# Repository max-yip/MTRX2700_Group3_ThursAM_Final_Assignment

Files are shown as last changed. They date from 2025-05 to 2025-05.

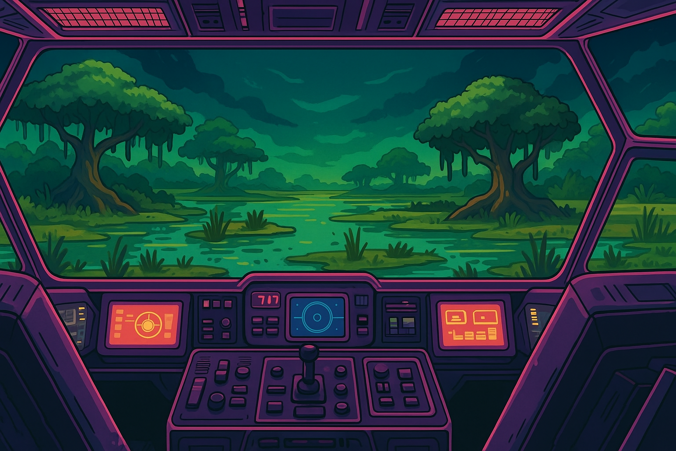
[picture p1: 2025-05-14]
code/GUI_interface/assets/space_bg_swamp.png

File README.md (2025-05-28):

# MTRX2700_Group3_ThursAM_Final_Assignment

## Group Members
Paul Akle 530483944 <br>
Max Yip 520434307 <br>
Siya Sharma 510451145 <br>
Shuvayu Banerjee 540752353 <br>

## Assignment Purpose
To design and implement proof-of-concept technology for a high-tech treasure hunt experience by incorporating a number of different
microcontroller subsystems, sensors, and an actuator.

## Roles and Responsibilities

### Paul Akle
- **Integration:**
  - Challenge 2 & 3 integration
- **Software Interfaces:**
  - Break beam sensor module
  - Servo motor control
  - Flexible potentiometer module
- **Design**
  - Phycial cardboard models (puzzles 2+3)

### Max Yip
- **Integration:**
  - Challenge 1 & 4 integration
- **Software Interfaces:**
  - PyQt GUI design and implementation
  - PTU module
  - Sensor data filtering and serialisation
- **Sensing and Detection:**
  - LDR color detection
- **Design & Documentation:**
  - CAD modeling

### Siya Sharma
- **Display and Sensing Interfaces:**
  - LCD display module
  - LDR sensor module
- **Game Design:**
  - Game mechanics and challenge development

### Shuvayu Banerjee
- **Mechanical Design:**
  - CAD modeling
  - Materials sourcing and procurement
- **Software Interfaces:**
  - Servo motor

## Repository Overview
### File Structure
```
CAD/                                   # All the CAD files (including STEP AND STL can be found here
code/
  ├── modules and interfaces/          # Individual modules that are not required for the challenges
  └── major_project_ptu/               # STM Project for Challenge 1
  └── GUI_interface/                   # PyQt6 GUI for Challenge 1
  └── puzzle_major_project/            # STM Project for Challenge 2 & 3
  └── major_project_lightsaber/        # STM Project for Challenge 4
minutes/                               # Meeting minutes
```

## Project Overview
<details>
  <summary>Challenge 1</summary>
  
  ### Triangulating the hidden planet location

  The player is tasked to locate the hidden planet by measuring the distances of the nearest 3 stars before the fuel runs out.
  
  ### How it works
  1. Users will be required to control the servos of the PTU through the GUI to adjust the lidar to point towards the correct planet.
  2. As the user moves the PTU, the GUI will display the distance and indicate whether the angle of the PTU is correct. The user will have to get the coordinates before moving onto the next planet.
  3. Once the player gets the distance or the timer runs out, the STM32 will signal the GUI to move onto the next planet.
  4. Once all the distances are obtained, it will reveal coordinates to the hidden planet.
  5. Move on to the next challenge: during the travel, the user encounters an asteroid field and is required to shoot them down.

  ### Code Structure Diagram
  puzzle2_2 drawio

  ### Additional Features
  - **Pop-up windows**  
    - At the beginning, to give the user the background of the game  
    - User feedback on whether the distances measured from the PTU are correct  
    - Final pop-up window directing the user to the next challenge  

  - **Chatbot**  
    - Friendly cat companion that gives hints to guide the user throughout the entire treasure hunt
  
</details>

<details>
  <summary>Challenge 2</summary>
  
  ### Asteroid Attack
  After locating the planet the player experiences an astroid field right before entering the planets atmosphere where 8 astroids must be sucessfully hit to make it to the planets surface.

  ### How it works
  1. The user will aim a laser beam and flick towards the astroid
  2. The IR beam breaker sensor will be placed on either side of the lasers path and will detect the object passing through
  3. Each time this occure one of the eight LEDs on the STM discovery board will light up untill all 8 astroids are destroyed

  ### Flowchart
  puzzle2_2 drawio

</details>
<details>
  <summary>Challenge 3</summary>
  
  ### Map Coordinates with Flexible Potentiometer
  After the user makes it to the surface of the planet they must now determine the correct coordinates of the crystal 

  ### How it works
  1. On a locating device there are two flexible potentiometers, one represents the x-ccordinate and the other represents the y-coordinates
  2. By applying pressure on different spots along the potentiometer will generate different values
  3. The interface will tell the user if they are closer or further from the true coordinates compared with their previous attempt
  4. After landing on the correct coordinates the display will tell the user to go to those coordinates on the grid
  5. A servo is intigrated with the determination of the correct coordinates, which when achieved will rotate 90 degrees to open the lid of the correct grid space
  6. An LDR inside this gridspace will detect the light and display a message on a LCD to retreive the crytal and place it in the hilt of the lightsaber

  ### Sersors + Actuators used
  1. 2x Flexible potentiometers
  2. Directional servo motor
  3. Light detecting resistor (LDR)
  4. Liquid-crystal Display (LCD)

  ### Flowchart
  puzzle3 drawio

</details>

<details>
  <summary>Challenge 4</summary>

  ### Assembling the Lightsaber
  The final step in this treasure hunt is to verify that the crystal obtained from challenge 3 is the correct one.

  ### How it works
  1. User will insert the crystal into the hole inside the lightsaber hilt.
  2. The colour detection system will determine the colour of the crystal.
  3. When the user presses a button, the LED will either glow green (if a green crystal is inserted), red (if a red crystal is inserted), or remain off if no colour is detected.

</details>

## Modules
<details>
<summary>GUI interface</summary>

### Summary
This module serves as the **GUI control panel** for user interaction with the **Pan-Tilt Unit (PTU)** in Challenge 1. It provides both **control** and **feedback** for PTU servo positions via UART communication, and handles **game logic** such as planet progression, fuel consumption, and hints.

### File Structure
```
main.py                 # Entry point to launch GUI
ui/
  ├── main_window.py    # Top-level window layout
  ├── center_panel.py   # Central panel with coordinate logic
  ├── left_panel.py     # Planet info and sliders
  └── right_panel.py    # Chatbot and status indicators
core/
  ├── logic.py          # Game logic handling (planet state, validation)
  └── serial_handler.py # Serial communication with STM32
assets/
  └── images/           # UI image resources
```

### Usage
1. **Connect** STM32 board with PTU attached via USB.
2. Ensure PyQT6 installed, build version is using python3.12.1
2. In `main_window.py` (around line 31), **ensure the correct COM port** is specified for the STM32 board.
3. Run the GUI:
  ```bash
  python3 main.py
  ```

### Functionalities

- **Sliders**:  
  - Two sliders control **pan** and **tilt** angles of the servos.
  
- **Next Planet Button**:  
  - Advances to the next planet once current target is complete.

- **Calculate Coordinate Button**:  
  - Validates all 3 distances and PTU orientation for accuracy.

- **Fuel Bar**:  
  - Decreases if the player inputs incorrect distance/orientation.

- **Chatbot**:  
  - Offers hints during the treasure hunt when prompted by user.

### Valid Input

- Ensure **serial format** in `serial_handler.py` matches the STM32 firmware.
- Correct **COM port** is configured in the GUI.
- Servo positions (pan/tilt) must match pre-defined **target coordinates** (to be added).

### Functions and Modularity

- `main.py`  
  - Initializes and launches the main GUI window.

- `serial_handler.py`  
  - Handles UART communication with STM32.

- `logic.py`  
  - Contains game logic, position validation, planet progression.

- `main_window.py`  
  - Assembles all UI panels and manages layout.

- `left_panel.py`  
  - Contains sliders and planet visuals.

- `center_panel.py`  
  - Displays coordinates, fuel bar, and validation controls.

- `right_panel.py`  
  - Manages chatbot interaction and game messages.

### Testing

- **Slider Limitations**:  
  - Cannot set slider values by clicking—must be **manually dragged** to send values to STM32 correctly.

- **Chatbot Testing**:  
  - Ask for hints multiple times to confirm chatbot randomness and reliability.

- **Functional Testing**:  
  - Interact with all controls:
    - Adjust pan/tilt sliders
    - Validate coordinates
    - Use next planet button
    - Trigger fuel bar reduction
    - Request hints via chatbot
    - Ensure serial communication and game logic run smoothly

</details>

<details>
  <summary>PTU</summary>

### Summary
This module enables interfacing with the Pan-Tilt Unit through UART. It controls:
- 2 servos (pan, tilt)
- 1 LIDAR-Lite v3 distance sensor
- 3-axis gyroscope (L3G4200D)
- 3-axis accelerometer (ADXL345)
- 3-axis magnetometer (HMC5883L)

This is the main interface for Challenge 1 where users must orient servos to take accurate distance measurements.

---

### Sub-modules

#### Servo Drivers
**File**: `ptu_servo.h`

##### Usage
- `HAL_StatusTypeDef initialise_ptu_pwm(TIM_HandleTypeDef *htim1, TIM_HandleTypeDef *htim2)`  
  Initializes timers 1 & 2 for the two servos.

- `void setServoPWM(uint16_t vertical_PWM, uint16_t horizontal_PWM)`  
  Sets pan and tilt servo PWM values.

- `void servo_command_parser(SerialPort *serial_port)`  
  Debugging parser (no serialization) to directly set PWM via serial.

##### Functionalities and Features
- Servo changes are triggered by serial interrupts from the GUI.
- Both servos can be controlled simultaneously, but the GUI allows one at a time.

##### Testing
- Print statements on GUI confirm servo positioning.
- Command parser allows standalone testing (bypassing serialization).
- PWM values are clamped to slider bounds.

---

#### LIDAR
**File**: `ptu_lidar.h`

##### Usage
- `void HAL_TIM_IC_CaptureCallback(TIM_HandleTypeDef *htim)`  
  Timer callback for PWM input (auto-triggered; do not call manually).

- `uint16_t last_period`  
  Stores the most recent measured distance in mm.

##### Functionalities and Features
- Distance is updated via interrupt on each pulse from LIDAR.
- Includes median filtering for noise reduction.
- Max reading capped at 4000 mm (4 meters).

##### Testing
- Test using objects at known distances (e.g. ruler).
- Validate units (mm) and output via GUI.
- Confirm proper serialisation to GUI.

---

#### Gyroscope and Accelerometer
**File**: `ptu_i2c.h`

##### Usage
- `void initialise_ptu_i2c(I2C_HandleTypeDef *i2c)`  
  Initializes I2C interface for sensors.

- `void read_gyro_data(I2C_HandleTypeDef *i2c, int16_t *yaw, int16_t *pitch, int16_t *roll)`  
  Reads gyroscope data.

- `void read_accel_data(I2C_HandleTypeDef *i2c, int16_t *acc_x, int16_t *acc_y, int16_t *acc_z)`  
  Reads accelerometer data.

##### Notes
- Currently unused, but intended for future Kalman filtering to estimate tilt.
- Will replace GUI dials with real-world orientation estimates.

##### Testing
- Output raw data via serial for verification.
- Connect to GUI and confirm readable, filtered data.
- Filter test: output should be ~0 if signal frequency < half window size.

---

#### Helper Modules

**`filters.h`**
- `void initFilters(Filter *filters, uint16_t init_value)`  
  Initializes sliding window filters.

- `uint16_t getMedian(Filter* filter, uint16_t new_value)`  
  Computes median-filtered output.

- `uint16_t getMovingAverage(Filter* filter, uint16_t new_value)`  
  Computes moving average output.

**`ptu_definitions.h`**
- Contains all sensor register mappings and I2C constants.

**`serial.h and serialisation.h`**
- Packs all sensor data and sends it to the GUI.
- Uses sentinel bytes and headers for reliable parsing.

</details>

<details>
  <summary>Flex pot sensor</summary>
  
### Flexible Potentiometer (flexpot.c)
### Summary
This module configures ADC1 on PC0 (ADC_IN6) and PC2 (ADC_IN8) to read input from two flexible potentiometers. It provides a simple API to initialize the ADC hardware and perform one-shot conversions on a specified channel, returning a discrete position value (1–6) or 0 to indicate no touch.

### Usage
1. Initialization
Call:
`FlexPot_Init();`

This:
  - Enables clocks for GPIOC and ADC1
  - Configures PC0 and PC2 in analog mode
  - Calibrates and enables ADC1

2. Reading a Position
To read from a specific potentiometer channel:
`uint8_t pos = FlexPot_GetPosition(channel);`
Where:
  - `channel` is `6` for PC0 or `8` for PC2
  - Return value pos is:
    - `0` if no touch (`raw < 100`)
    - `1–6` depending on pressure/location along the strip

### Valid Input

- channel must be:
    - `6` → PC0 → ADC_IN6
    - `8` → PC2 → ADC_IN8

- Internally:
    - Raw ADC values < 100 are considered no touch and return 0
    - Values ≥ 100 are linearly mapped to positions 1–6
      (1 = bottom, 6 = top of the strip)

### Functions and Modularity

- `void FlexPot_Init(void)`
 Initializes GPIOC and ADC1:
    - Enables clocks
    - Sets PC0 and PC2 to analog mode
    - Calibrates and powers on ADC1

- `uint8_t FlexPot_GetPosition(uint8_t channel)`
Reads the flexible potentiometer:
  - Sets the selected ADC channel (6 or 8)
  - Starts and waits for ADC conversion
  - Reads `ADC1->DR`
  - Applies a "no-touch" threshold
  - Maps 12-bit ADC value (0–4095) to discrete values `0–6`

### Testing

- No Touch Test:
Leave the potentiometer untouched → should return 0

- Endpoint Test:
Press firmly at the start or end of the strip → should return 1 or 6

- Integration Test:
In your puzzle game, read X/Y positions using:

`uint8_t x = FlexPot_GetPosition(6);
uint8_t y = FlexPot_GetPosition(8);`

Send both values over UART periodically and confirm the output matches physical input location.

</details>

<details>
  <summary>Break Beam Sensor </summary>
  
### IR Beam Breaker Sensor (beam.c)
  
### Summary
This module configures PC1 as an EXTI1 (falling‐edge) interrupt input to detect when an IR beam is broken. Each beam break increments a counter (`beam_count`, up to 8) and lights the corresponding Discovery-board LED (PE8…PE15). A simple API lets you query or reset the count (and LEDs).
### Usage
1. Initialization
At the start of your program, call `Beam_Init();`
This:
    - Enables GPIOC and GPIOE clocks
    - Configures PC1 as an EXTI1 input with falling-edge interrupt
    - Enables EXTI1 interrupt in NVIC
    - Sets up PE8–PE15 as outputs for LED indication

2. Reading the Count
In your application code, use:
`uint8_t n = Beam_GetCount();`
This returns the number of beam breaks detected so far (max 8).

2. Resetting the Count and LEDs
To reset the counter and turn off LEDs:
`Beam_ResetCount();`

### Valid Input
- An object must break the IR beam, pulling PC1 low and triggering a falling edge.
- Only transitions from high to low increment `beam_count` (debounced via hardware or design).
- The counter saturates at 8; additional breaks do not increase the count or light further LEDs.
- No input (i.e., beam never broken) is treated as a failure condition in the game.

### Functions and Modularity
- `void Beam_Init(void)`
Initializes GPIOC and GPIOE. Configures PC1 for EXTI1 (falling edge) and sets PE8–PE15 as LED outputs.
- `uint8_t Beam_GetCount(void)`
Returns the current value of beam_count.
- `void Beam_ResetCount(void)`
Resets beam_count to 0 and turns off all LEDs.
- `void HAL_GPIO_EXTI_Callback(uint16_t GPIO_Pin)`
Called automatically by HAL on EXTI interrupts. If the pin is PC1 and it reads low:
  - Increments `beam_count` (if < 8)
  - Lights the corresponding LED (PE8 + count index)

### Testing
To test the boundary conditions the beam breaks more than eight times which should result in no further LEDs lighting up or overflow to occur.
To test integration the main file code with the flex-pot code is tested to ensure the two modules operate without interfering (e.g. ADC vs EXTI).
1. Boundary Test:
Trigger the beam more than 8 times. The count should stop incrementing and no extra LEDs should light.

2. Integration Test:
Run the beam module alongside other sensor modules (e.g., Flex Potentiometer using ADC). Verify:
    - EXTI and ADC operate independently.
    - No conflicts or race conditions between modules.

</details>

<details>
  <summary>LCD display</summary>
  
  ### Summary
  
  This module provides an interface for controlling a 16x2 HD44780-compatible LCD over I2C using STM32 HAL libraries. It uses an I2C I/O expander (e.g., PCF8574) to communicate with the LCD in 4-bit mode. This reduces GPIO usage and simplifies wiring, ideal for STM32CubeMX-based projects.

The module allows for easy initialization, cursor control, string display, and command-level manipulation. 

The LCD is connected to GPIO port D using the following pin mapping:
- GND --> GND
- VDD --> 5V
- SCL --PA6
- SDA --> PA7

The module is designed for portability and ease of integration with STM32CubeMX-based projects.

  ### Usage

#### 1. Include the module
In main.c or any relevant source file:
`#include "i2c.h"`

#### 2. Include the module
Initialize LCD in your main function
```
HD44780_Init(2);                  // 2-line LCD
HD44780_Clear();
HD44780_PrintStr("Place crystal on handle!");
```

  ### Valid Input
1. Rows: 0 or 1
2. Columns: 0 to 15
3. Characters: Standard ASCII text (the LCD does not support Unicode)
4. Strings: Null-terminated (char *), max 16 characters per line (extra characters wrap if not managed)

  ### Functions 

- `void void HD44780_Init(uint8_t rows)`
Initializes the LCD in 4-bit mode.

- `void HD44780_Clear(void)`
Clears the LCD display.

- `void HD44780_Init(uint8_t rows)`
Initializes the LCD in 4-bit mode with the specified number of rows.

- `void HD44780_Clear(void)`
Clears the display.

- `void HD44780_SetCursor(uint8_t col, uint8_t row)`
Sets the cursor to the given column and row.

- `void HD44780_PrintStr(const char str[])`
Prints a null-terminated string.

- `void HD44780_Cursor(void)`
Shows the cursor.

- `void HD44780_NoCursor(void)`
Hides the cursor.

- `void HD44780_Blink(void)`
Enables blinking cursor.

- `void HD44780_NoBlink(void)`
Disables blinking cursor.

- `void HD44780_Backlight(void)`
Turns on the backlight.

- `void HD44780_NoBacklight(void)`
Turns off the backlight.

- `void HD44780_CreateSpecialChar(uint8_t index, uint8_t data[])`
Loads a custom character (up to 8).

- `void HD44780_PrintSpecialChar(uint8_t index)`
Prints a previously created special character.

- `void HD44780_ScrollDisplayLeft(void) / HD44780_ScrollDisplayRight(void)`
Scrolls display left/right.

  ### Modularity
All functions are encapsulated in `i2c.c` and `i2c.h`. The module relies solely on HAL I2C and minimal MCU core resources (DWT for delay). It can be easily reused across STM32 projects with similar hardware configuration.

  ### Testing 
1. Confirm LCD initializes and displays static text using `HD44780_PrintStr()`.
2. Test cursor positioning with `HD44780_SetCursor(row, col)`.
3. Test scrolling and blinking using display control functions.
4. Load and print custom characters with `HD44780_CreateSpecialChar()` and `HD44780_PrintSpecialChar()`.

#### Debug Tips
1. Ensure correct I2C address (0x27 << 1 for PCF8574).
2. Check LCD contrast by adjusting the potentiometer on V0.
3. If LCD remains blank:
     - Verify I2C connection (SCL, SDA continuity).Confirm LCD receives enable pulse (use oscilloscope).
     - Check backlight and 5V power supply.

</details>
<details>
  <summary>LDR</summary>

### Summary
This module uses an LDR (Light Dependent Resistor) for two purposes:
1. **Light Detection**  
   - Measures ambient brightness.
   - Compares against a preset threshold to trigger logic changes.

2. **Colour Detection**  
   - Detects the amount of reflected light when red, green, and blue LEDs are sequentially illuminated.
   - Determines the dominant reflected wavelength to identify the surface colour.

---

### Sub-modules

#### Colour Detection State Machine  
**File**: `colour_detector.h`

##### Description
A state machine implemented via `switch-case` inside a timer callback:
- **States**:  
  `INIT → RED_ON → READ_RED → GREEN_ON → READ_GREEN → BLUE_ON → READ_BLUE → DETECT_COLOUR`

- **Calibration**:  
  On first run (`calibrate = 0`), records initial ambient brightness to normalize readings.

- **Debugging**:  
  When colour is detected, an optional final state transmits a string over serial for monitoring.

##### Usage
- Timer interrupt calls the `handleStateMachine()` function at a fixed interval.
- LED GPIOs are toggled within each state to control colour sequencing.

---

#### ADC Functions  
**File**: `adc.c`

##### Core Functions
- `void initialiseSingleADC()`  
  Manually configures ADC1 to single-shot mode.

- `uint16_t singleReadADC()`  
  Performs a one-time read of the ADC value, used in the colour detection state machine.

##### Optional Utilities
- `void continuousReadSingleChannelADC()`  
  Continuously polls a single ADC channel in a blocking loop using the `ISR` register.

- `void SingleReadMultiChannelADC()`  
  Reads multiple channels on the same ADC (currently unused in this module but available for expansion).

---

### Functionalities and Features
- Ambient light detection with threshold-triggered variable setting.
- RGB LED-controlled surface reflection sensing to classify colours.
- Compact state machine for cyclic LED control and ADC reading.
- Lightweight implementation using timer-driven ADC sampling.

---

### Usage

```c
int main(void) {
    enableGPIODLEDS();
    enableGPIOClocks();

    serialInitialise(BAUD_115200, &USART1_PORT, 0x00);

    initialiseSingleADC();

    // Start colour detection state machine on timer callback
    setTIM2Callback(&handleStateMachine);
    init_TIM2(50); // Timer interval set to 50ms
}
```

---

### Testing
- Use serial output to confirm detection states and transitions.
- Calibrate under various lighting conditions to test ambient compensation.
- Use known-colour surfaces and compare detection accuracy.
- Evaluate ADC signal stability under continuous and single-shot reads.

</details>

<details>
  <summary>Servo Motor</summary>

  ### Summary
This module allows control of a servo motor via PWM (TIM2 CH1) on the STM32F3DISCOVERY board. Pressing the blue user button (PA0) triggers an rising-edge EXTI0 interrupt that calls a callback function, rotating the servo to a fixed angle (90°). The PWM signal is continuously generated on PA15 (TIM2_CH1). All hardware logic is modularised into a clean `servo.c` and `servo.h` interface.

  ### Usage
This section explains how to use the digital button (PA0) for controlling the servo motor. All functionality is interrupt-based, so no button polling or delay loops are needed.

---

#### 1.Include the Header:
At the top of your `main.c` file, include the servo module:
```c
#include "servo.h"
```
2. Setup in main():
Call these functions once in `main()` to initialize everything:

```c
enable_clocks();                      
enableGPIOAButton();                   

on_button_press = &rotate_servo_90;         

enable_interrupt();                   
```
3. Main Loop:
loop forever and there is nothing happening in the main while loop since everything is interrupt driven:
```c
while (1)
  {
    /* USER CODE END WHILE */

    /* USER CODE BEGIN 3 */
  }
```
4. What Happens:
* When the system powers on, all required peripherals (GPIOs, I2C, SPI, USB, and TIM2) are initialized.
* Timer 2 is started to generate a continuous PWM signal used to control a servo motor.
* The blue user button (PA0) is configured to trigger an interrupt when pressed.
* A call-back function is assigned to run automatically whenever the button is pressed.
* Once the interrupt is enabled, the program enters an infinite loop — but nothing happens here because the logic is interrupt-driven.
* When the user presses the button, the rising edge triggers an interrupt in the background.
* This causes the assigned servo-control function to run, which updates the PWM signal’s duty cycle.
* The updated PWM pulse tells the servo to rotate to a new position (90°).
* No repeated button presses will move the servo again unless the PWM value is updated again.
  
  ### Valid Input
The module expects the following valid inputs and formats:

* Button Press	- The user presses the on-board button (PA0), triggering the EXTI0 interrupt.

  ### Functions and Modularity
The code is separated into a header (servo.h) and implementation (servo.c) to support clean modularity and easy reuse.

**Functions:**

#### `enable_clocks()`
**Purpose:**  
Turns on the clocks (power) to the GPIO ports A, C, and E.

**When to call it:**  
At the beginning of your `main()` function — before setting up pins or using any peripherals.

---

### `void enableGPIOAButton(void)`
**Purpose**:  
Configures PA0 (the user button) as a digital input.

**How it Works**:  
Clears the mode bits in `GPIOA->MODER` for pin 0, putting it in input mode.

**When to Call**:  
Call once during setup, after clocks are enabled and before enabling interrupts.

---

### `void enable_interrupt(void)`
**Purpose**:  
Sets up external interrupts on PA0 to detect button presses.

**How it Works**:
- Enables the SYSCFG peripheral.
- Maps PA0 to EXTI0 (external interrupt line 0).
- Configures EXTI0 to trigger on a rising edge (i.e., button press).
- Enables EXTI0 in the NVIC (Nested Vectored Interrupt Controller).
- Globally enables interrupts using `__enable_irq()`.

**When to Call**:  
Call after assigning `on_button_press` and after enabling clocks and GPIOA input. Only needs to be called once.

---

### `void (*on_button_press)()`
**Purpose**:  
A function pointer that stores the action to take when the button is pressed (e.g., rotate the servo).

**How it Works**:  
You assign this in `main()` like so:  
```c
on_button_press = &rotate_servo_90;
```

#### `EXTI0_IRQHandler(void)`
**Purpose:**  
This is the interrupt service routine (ISR) for button press.

**What it does:**  
* When PA0 is pressed, this runs automatically
* It checks if on_button_press is set (not NULL)
* If set → it runs that function (toggleLED())
* Clears the EXTI0 interrupt flag

**When it runs:**  
Every time the user presses the button (rising edge on PA0).

---

### `rotate_servo_90(void)`

**Purpose**  
Moves the servo motor to the 90-degree position using PWM signals.

**How it Works**  
This function sets the compare values of TIM2’s channels (CCR1 and CCR2) to `1800`, which corresponds to a pulse width of approximately **1.5ms**. That’s the standard signal to tell most hobby servos to move to the **center or 90°** position.  

The PWM timer (already running in the background) uses these values to continuously send the correct high pulse width to the servo.

- `TIM2->CCR1 = 1800;`  
- `TIM2->CCR2 = 1800;`  

This assumes that the timer is configured for a **20ms period (50Hz)**, so:
- ~1ms pulse → 0°
- ~1.5ms pulse → 90°
- ~2ms pulse → 180°

**When to Call It**  
- You assign this function to the `on_button_press` pointer in `main()`.
- When the button is pressed, the EXTI0 interrupt fires and automatically calls this function.

  ### Testing 
This section shows how to test the servo code reliably, not just by observation but also using in-code checks.

---

#### Button Press Test

**Goal:** Check that pressing the blue user button rotates the servo.

**Steps:**
1. Connect servo:
   - Signal: PA15
   - VCC: 5V
   - GND: GND
2. Flash the code and run the board.
3. Press the user button.

**Expected:** Servo rotates to the 90° position.

---

#### Debug with LED Toggle

**Goal:** Confirm code execution using an LED.

**How:**
Add this to `rotate_servo_90()`:
```c
GPIOE->ODR ^= GPIO_ODR_9; // Toggle LED on each press
```

</details>

Code from **MTRX2700-2025** was used and refactored, and code from **ThursAM_Group6_CLab** was used in this assignment.

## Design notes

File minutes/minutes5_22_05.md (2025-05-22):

## Meeting Details 
# MTRX Group #3 
**Date:** 22/05/2025  
**Time:** 9:00 AM
**Location:** Tutorial session  
**Meeting Type:** Design and interface finalisation, discussing working parts   

## Attendance  
| Name | Status | Notes |
|---|---|---|
| Max Yip | Present  |  |
| Aditya Kathane | Present | Left early |
| Siya Sharma | Present  |  |
| Paul Akle | Present  |  |
| Shuvayu Benerjee | Present  |  |

## Agenda  
- [x] **Item 1** - Implement game logic
- [x] **Item 2** - Finalise current sensor interfaces
- [x] **Item 3** - Integrate interfaces to perform puzzles

## Action Items  
| Task | Assigned To | Due Date | Status |
|---|---|---|---|
| Build physical game interface + Integration| Paul Akle | Week 12 | In Progress |
| Try to get ldr colour detection working and finish up puzzle 1 game logic | Max Yip | Week 12 | In Progress |
| Servo Interface | Aditya Kathane | Week 9 | Unknown |
| LDR + LCD screen interface | Siya Sharma | Week 12 | Completed |
| 3D print required objects | all | Week 12 | Completed  |
| Readme for servo | Shuvayu Benerjee | Week 12 | In Progress  |

## Next Steps  
- **Next Meeting:** In-person meeting next Monday (27/5/25)  
- **Objectives for Next Meeting:**  
  - [ ] Objective 1: Complete all sensor interfaces 
  - [ ] Objective 2: Implement integration of modules
  - [ ] Objective 3: Finsh Game logic code for puzzles
  - [ ] Objective 4: Write up ReadMe

---
*End of Meeting Minutes*

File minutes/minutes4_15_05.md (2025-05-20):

## Meeting Details 
# MTRX Group #3 
**Date:** 15/05/2025  
**Time:** 10:00 AM
**Location:** Tutorial session  
**Meeting Type:** Design and interface finalisation, discussing working parts   

## Attendance  
| Name | Status | Notes |
|---|---|---|
| Max Yip | Present  |  |
| Aditya Kathane | Absent  |  |
| Siya Sharma | Present  |  |
| Paul Akle | Present  |  |
| Shuvayu Benerjee | Present  |  |

## Agenda  
- [x] **Item 1** - Implement game logic
- [x] **Item 2** - Finalise current sensor interfaces
- [x] **Item 3** - Integrate interfaces to perform puzzles

## Action Items  
| Task | Assigned To | Due Date | Status |
|---|---|---|---|
| Build physical game interface + Integration| Paul Akle | Week 12 | In Progress |
| Try to get ldr colour detection working and finish up puzzle 1 game logic | Max Yip | Week 12 | In Progress |
| Servo Interface | Aditya Kathane | Week 9 | Unknown |
| LDR + LCD screen interface | Siya Sharma | Week 12 | In pogress |
| 3D print required objects | all | Week 12 | Completed  |
| servo code and readme section of the servo | Shuvayu Benerjee | Week 12 | In Progress  |

## Next Steps  
- **Next Meeting:** In-person meeting next Monday (19/5/25)  
- **Objectives for Next Meeting:**  
  - [ ] Objective 1: Complete all sensor interfaces 
  - [ ] Objective 2: Implement integration of modules
  - [ ] Objective 3: Finsh Game logic code for puzzles

---
*End of Meeting Minutes*

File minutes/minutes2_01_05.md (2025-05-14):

## Meeting Details 
# MTRX Group #3 
**Date:** 01/05/2025  
**Time:** 10:00 AM
**Location:** Tutorial session  
**Meeting Type:** Design and interface finalisation   

## Attendance  
| Name | Status | Notes |
|---|---|---|
| Max Yip | Present  |  |
| Aditya Kathane | Absent  | Sick  |
| Siya Sharma | Absent  | Personal reasons |
| Paul Akle | Present  |  |
| Shuvayu Benerjee | Present  |  |

## Agenda  
- [x] **Item 1** - Create a final task description 
- [x] **Item 2** - Finalise current sensor interfaces
- [x] **Item 3** - Create interface for servo and LDR
- [ ] **Item 4** - Begin designing physical interfaces (Planets and Grid)

## Action Items  
| Task | Assigned To | Due Date | Status |
|---|---|---|---|
| Filter code + puzzle 2 design | Paul Akle | Week 10 | In Progress |
| Filter code + lidar and refractor code | Max Yip | Week 10 | In Progress |
| Servo Interface | Aditya Kathane | Week 10 | Unknown |
| LDR interface | Siya Sharma | Week 10 | Unknown |
| Purchase extra flexible potentiometer | all | Week 10 | In Progress  |
| Design planet for puzzle 1 | Shuvayu Benerjee | Week 10 | In Progress  |

## Next Steps  
- **Next Meeting:** In-person meeting next Wednesay (7/5/25)  
- **Objectives for Next Meeting:**  
  - [ ] Objective 1: Complete all tasks before next Thursday 
  - [ ] Objective 2: Have plan for integration ready to begin and implement

---
*End of Meeting Minutes*

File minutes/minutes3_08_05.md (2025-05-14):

## Meeting Details 
# MTRX Group #3 
**Date:** 08/05/2025  
**Time:** 9:00 AM
**Location:** Tutorial session  
**Meeting Type:** Design and interface finalisation, discussing working parts   

## Attendance  
| Name | Status | Notes |
|---|---|---|
| Max Yip | Present  |  |
| Aditya Kathane | Absent  | Preparing for other exam  |
| Siya Sharma | Present  |  |
| Paul Akle | Present  |  |
| Shuvayu Benerjee | Present  |  |

## Agenda  
- [x] **Item 1** - Write up a detailed summary of all parts of the major project and start on progress report due next week 
- [x] **Item 2** - Finalise current sensor interfaces
- [x] **Item 3** - Create interface for servo and LDR
- [ ] **Item 4** - Begin designing physical interfaces (Planets and Grid)

## Action Items  
| Task | Assigned To | Due Date | Status |
|---|---|---|---|
| Filter code + puzzle 2 design | Paul Akle | Week 11 | In Progress |
| Filter code + lidar and refractor code | Max Yip | Week 11 | In Progress |
| Servo Interface | Aditya Kathane | Week 11 | Unknown |
| LDR + LCD screen interface | Siya Sharma | Week 11 | In pogress |
| 3D print required objects | all | Week 11 | In Progress  |
| Design planet for puzzle 1 + servo interface | Shuvayu Benerjee | Week 11 | In Progress  |

## Next Steps  
- **Next Meeting:** In-person meeting next Monday (12/5/25)  
- **Objectives for Next Meeting:**  
  - [ ] Objective 1: Complete filter signal code 
  - [ ] Objective 2: Have plan for integration ready to begin and implement
  - [ ] Objective 3: Start Game logic for puzzle 1

---
*End of Meeting Minutes*

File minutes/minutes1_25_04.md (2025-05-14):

## Meeting Details 
# MTRX Group #3 
**Date:** 25/04/2025  
**Time:** 10:00 AM 
**Location:** Zoom Meeting  
**Meeting Type:** Task conceptialisation and brainstorm 

## Attendance  
| Name | Status | Notes |
|---|---|---|
| Max Yip | Present  |  |
| Aditya Kathane | Absent  |  |
| Siya Sharma | Present  |  |
| Paul Akle | Present  |  |

## Agenda  
- [x] **Item 1** - Demonstrate current ideas and challenges
- [x] **Item 2** - Brainstorm new ideas
- [x] **Item 3** - Create a final task description 
- [ ] **Item 4** - Design of system diagrams 

## Action Items  
| Task | Assigned To | Due Date | Status |
|---|---|---|---|
| IR beam Breaker Interface | Paul Akle | Week 9 | In Progress |
| Create project code base | Max Yip | Week 9 | In Progress |
| Servo Interface | Aditya Kathane | Week 9 | Unknown |
| Stages design | Siya Sharma | Week 9 | In Progress  |

## Next Steps  
- **Next Meeting:** Remote call before next Thursday (Date TBC)  
- **Objectives for Next Meeting:**  
  - [ ] Objective 1: Complete all tasks before next Thursday 
  - [ ] Objective 2: Have plan for integration ready to begin and implement

---
*End of Meeting Minutes*

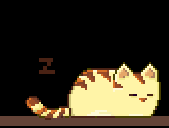
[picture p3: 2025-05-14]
code/GUI_interface/assets/cat_cropped.gif

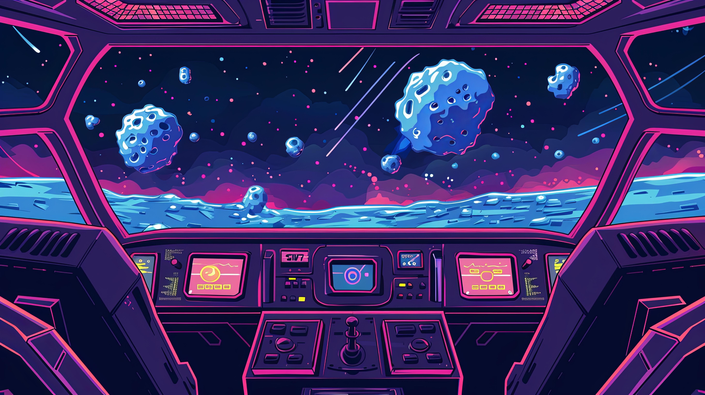
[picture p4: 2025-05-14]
code/GUI_interface/assets/space_bg2.jpg

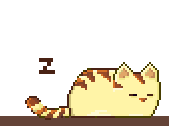
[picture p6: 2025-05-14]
code/GUI_interface/assets/cat_nobg.gif

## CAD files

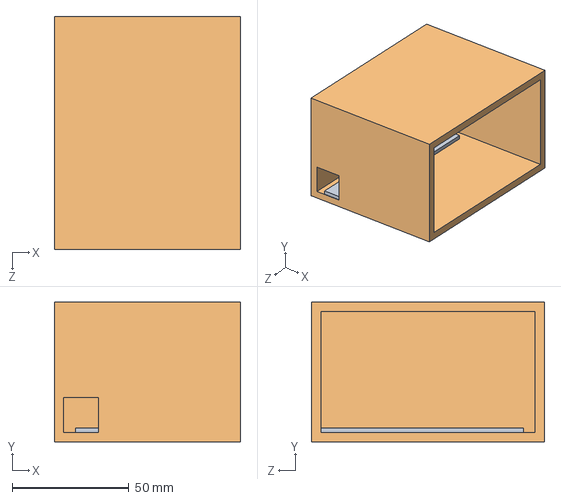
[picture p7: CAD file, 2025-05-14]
CAD/sensor_box.SLDASM
80.0 x 60.0 x 100.0 mm
Pressure Sensor Box
Flex pot placeholder

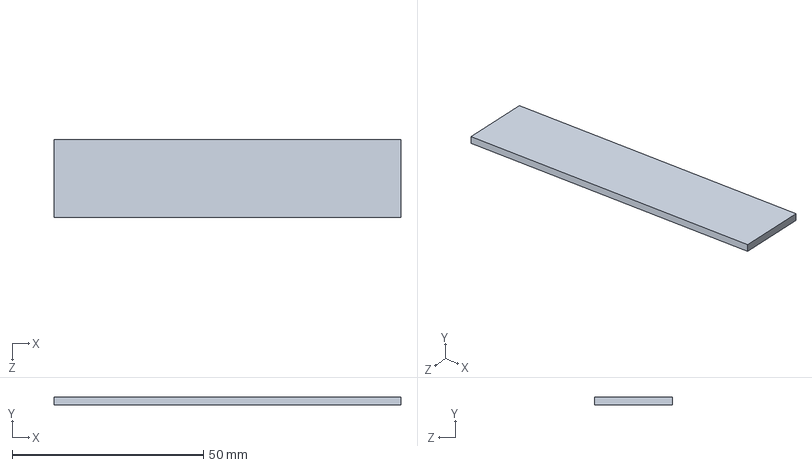
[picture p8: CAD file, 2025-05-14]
CAD/Flex pot placeholder.SLDPRT
90.8 x 2.00 x 20.3 mm

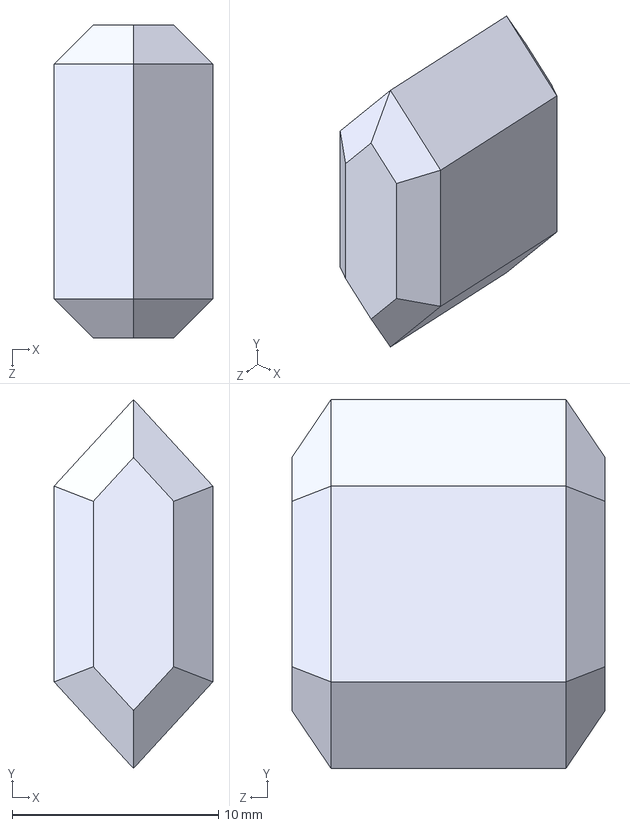
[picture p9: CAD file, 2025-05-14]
CAD/crystal.STEP
7.70 x 17.9 x 15.2 mm

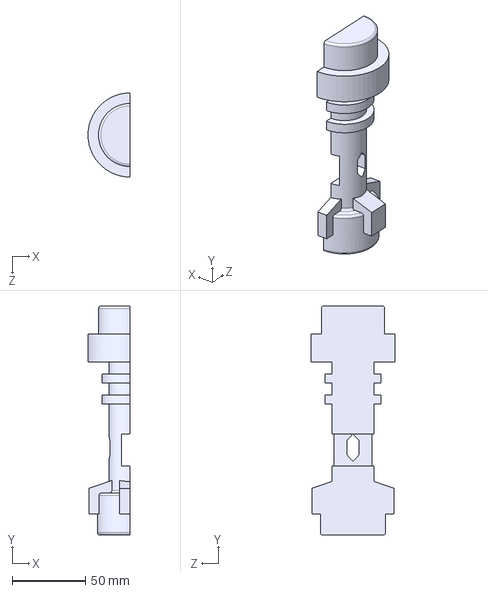
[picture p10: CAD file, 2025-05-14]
CAD/hilt2.STEP
28.8 x 156.8 x 57.6 mm

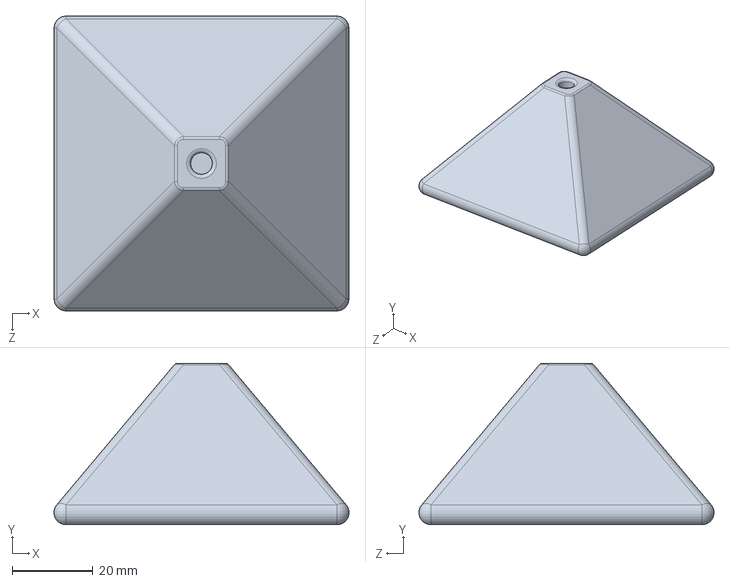
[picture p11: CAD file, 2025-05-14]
CAD/BASE_MTRX2700.SLDPRT
73.1 x 40.0 x 73.1 mm

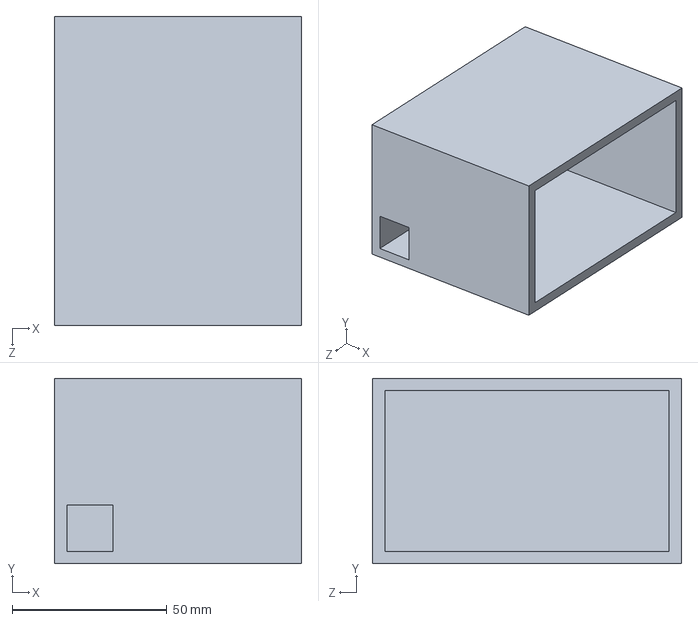
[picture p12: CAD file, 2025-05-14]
CAD/Pressure Sensor Box.SLDPRT
80.0 x 60.0 x 100.0 mm

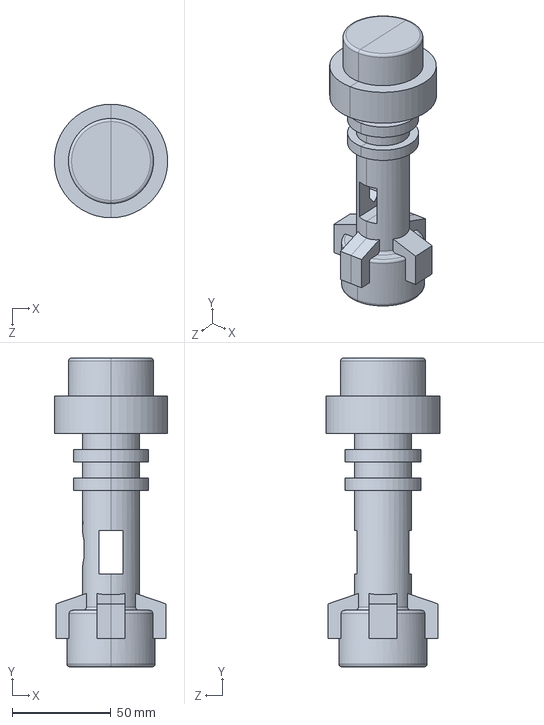
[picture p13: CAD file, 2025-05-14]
CAD/lightsaber hilt.SLDPRT
57.5 x 156.8 x 57.6 mm

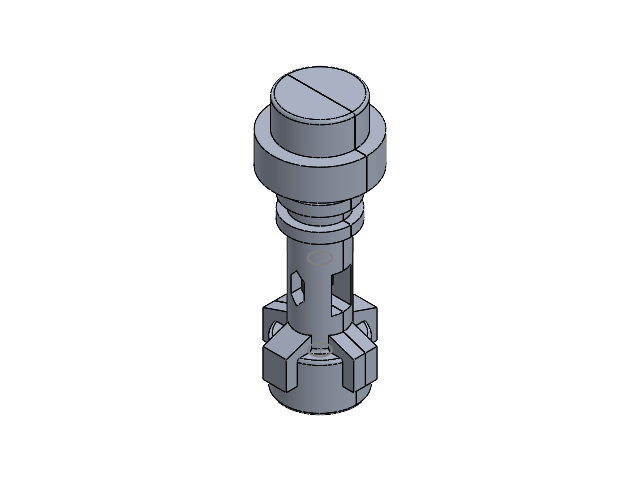
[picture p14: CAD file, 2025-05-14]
CAD/crystal inside lightsaber.SLDASM
crystal
lightsaber hilt

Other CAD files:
CAD/hilt1.STEP
CAD/BASE_MTRX2700.STL
CAD/base_option2.SLDPRT
CAD/base_option2.STL
CAD/crystal.SLDPRT
CAD/crystal.STL
CAD/hilt1.SLDPRT
CAD/hilt1.STL
CAD/hilt2.SLDPRT
CAD/hilt2.STL

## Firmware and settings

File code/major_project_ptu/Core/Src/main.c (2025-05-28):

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
/* Includes ------------------------------------------------------------------*/
#include "main.h"

/* USER CODE BEGIN Includes */
#include "ptu_definitions.h"
#include "ptu_i2c.h"
#include "ptu_servo.h"
#include "ptu_lidar.h"
#include "serial.h"
#include "serialise.h"
#include "gpio.h"
#include "filters.h"
#include <math.h>
/* USER CODE END Includes */

I2C_HandleTypeDef hi2c1;

SPI_HandleTypeDef hspi1;

PCD_HandleTypeDef hpcd_USB_FS;

// timer definition for lidar pwm
TIM_HandleTypeDef htim1;
TIM_HandleTypeDef htim2;


void SystemClock_Config(void);
static void MX_GPIO_Init(void);
static void MX_I2C1_Init(void);
static void MX_SPI1_Init(void);
static void MX_USB_PCD_Init(void);
static void MX_TIM2_Init(void);
static void MX_TIM1_Init(void);
/**
  * @brief  The application entry point.
  * @retval int
  */
int main(void)
{

  /* USER CODE BEGIN 1 */
//	Pin connections
//	SCL to PB6
//	SDA to PB7
//	PWM1 to PA1
//	PWM2 to PA15
//	LASPWM to PA8
//	rest to ground

  /* USER CODE END 1 */

  /* MCU Configuration--------------------------------------------------------*/

  /* Reset of all peripherals, Initializes the Flash interface and the Systick. */
  HAL_Init();

  /* Configure the system clock */
  SystemClock_Config();

  /* Initialize all configured peripherals */
  MX_GPIO_Init();
  MX_I2C1_Init();
  MX_SPI1_Init();
  MX_USB_PCD_Init();
  MX_TIM2_Init();
  MX_TIM1_Init();
  /* USER CODE BEGIN 2 */


	  // Initialise UART serial communication at 115200 baud
	  // and set the command parser callback for servo control
	  serialInitialise(BAUD_115200, &USART1_PORT, &servo_command_parser);

	  // Enable receive interrupt for non-blocking serial input
	  serialReceiveInterrupt(&USART1_PORT);

	  // Initialise I2C interface for the pan-tilt unit (gyro, accel, etc.)
	  initialise_ptu_i2c(&hi2c1);

	  uint8_t return_value = 0x00;

	  return_value = HAL_I2C_Mem_Write(&hi2c1, LIDAR_WR, 0x00, 1, &return_value, 1, 10);
	  if (return_value != HAL_OK) {
	      // Handle I2C error
	      Error_Handler();
	  }

	  return_value = initialise_ptu_pwm(&htim1, &htim2);
	  if (return_value != HAL_OK) {
	      // Handle PWM init failure
	      Error_Handler();
	  }

	  // Create and initialise an array of median filters for sensor data
	  Filter dataFilters[NUM_DATA];
	  initFilters(dataFilters, 0);  // Fill filter windows with initial value 0

	  // Variables to hold filtered sensor data
	  uint16_t filtered_lidar;
	  int16_t filtered_roll, filtered_pitch, filtered_yaw;
	  int16_t filtered_acc_x, filtered_acc_y, filtered_acc_z;

	  // Variables to hold raw sensor data
	  int16_t yaw = 0, pitch = 0, roll = 0;
	  int16_t ax = 0, ay = 0, az = 0;

  /* USER CODE END 2 */

  /* Infinite loop */
  /* USER CODE BEGIN WHILE */
  while (1)
  {
    /* USER CODE END WHILE */

	    // Read raw gyro and accelerometer data from IMU
	    get_gyro_accel(&hi2c1, &yaw, &pitch, &roll, &ax, &ay, &az);

	    // Apply median filtering to raw sensor data to remove noise
	    filter_all_sensor_data(dataFilters, last_period,
	                           roll, pitch, yaw,
	                           ax, ay, az,
	                           &filtered_lidar,
	                           &filtered_roll, &filtered_pitch, &filtered_yaw,
	                           &filtered_acc_x, &filtered_acc_y, &filtered_acc_z);



		// ===== SERIAL DEBUG =====
		// send data without serialisation, lidar distance set as 0 as i2c doesnt work
//		uint8_t string_to_send[128];
//		sprintf(string_to_send, "last period: %hu, lidar distance: %hu, roll: %hd, pitch: %hd, yaw: %hd\r\n", filtered_lidar, 0, filtered_roll, filtered_pitch, filtered_yaw);
//		transmitString(string_to_send, &USART1_PORT);



		// Construct a sensor data packet and send over serial
	    sendSensorData(filtered_roll, filtered_pitch, filtered_yaw,
	                     filtered_acc_x, filtered_acc_y, filtered_acc_z,
	                     filtered_lidar, &USART1_PORT);


//		// Read a data packet from serial

		uint8_t data_packet_input_buffer[32] = {0};

//		Read header
		uint16_t header_size = serialInputPacketHeader((char *)data_packet_input_buffer, &USART1_PORT);
		if (header_size == 0) {
		    // Handle header receive failure
		}


		/* USER CODE BEGIN 3 */
	}
  /* USER CODE END 3 */
}

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


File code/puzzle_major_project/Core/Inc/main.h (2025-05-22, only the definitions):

#define DRDY_Pin GPIO_PIN_2
#define DRDY_GPIO_Port GPIOE
#define CS_I2C_SPI_Pin GPIO_PIN_3
#define CS_I2C_SPI_GPIO_Port GPIOE
#define MEMS_INT3_Pin GPIO_PIN_4
#define MEMS_INT3_GPIO_Port GPIOE
#define MEMS_INT4_Pin GPIO_PIN_5
#define MEMS_INT4_GPIO_Port GPIOE
#define OSC32_IN_Pin GPIO_PIN_14
#define OSC32_IN_GPIO_Port GPIOC
#define OSC32_OUT_Pin GPIO_PIN_15
#define OSC32_OUT_GPIO_Port GPIOC
#define OSC_IN_Pin GPIO_PIN_0
#define OSC_IN_GPIO_Port GPIOF
#define OSC_OUT_Pin GPIO_PIN_1
#define OSC_OUT_GPIO_Port GPIOF
#define B1_Pin GPIO_PIN_0
#define B1_GPIO_Port GPIOA
#define SPI1_SCK_Pin GPIO_PIN_5
#define SPI1_SCK_GPIO_Port GPIOA
#define SPI1_MISO_Pin GPIO_PIN_6
#define SPI1_MISO_GPIO_Port GPIOA
#define SPI1_MISOA7_Pin GPIO_PIN_7
#define SPI1_MISOA7_GPIO_Port GPIOA
#define LD4_Pin GPIO_PIN_8
#define LD4_GPIO_Port GPIOE
#define LD3_Pin GPIO_PIN_9
#define LD3_GPIO_Port GPIOE
#define LD5_Pin GPIO_PIN_10
#define LD5_GPIO_Port GPIOE
#define LD7_Pin GPIO_PIN_11
#define LD7_GPIO_Port GPIOE
#define LD9_Pin GPIO_PIN_12
#define LD9_GPIO_Port GPIOE
#define LD10_Pin GPIO_PIN_13
#define LD10_GPIO_Port GPIOE
#define LD8_Pin GPIO_PIN_14
#define LD8_GPIO_Port GPIOE
#define LD6_Pin GPIO_PIN_15
#define LD6_GPIO_Port GPIOE
#define DM_Pin GPIO_PIN_11
#define DM_GPIO_Port GPIOA
#define DP_Pin GPIO_PIN_12
#define DP_GPIO_Port GPIOA
#define SWDIO_Pin GPIO_PIN_13
#define SWDIO_GPIO_Port GPIOA
#define SWCLK_Pin GPIO_PIN_14
#define SWCLK_GPIO_Port GPIOA
#define SWO_Pin GPIO_PIN_3
#define SWO_GPIO_Port GPIOB
#define I2C1_SCL_Pin GPIO_PIN_6
#define I2C1_SCL_GPIO_Port GPIOB
#define I2C1_SDA_Pin GPIO_PIN_7
#define I2C1_SDA_GPIO_Port GPIOB
#define MEMS_INT1_Pin GPIO_PIN_0
#define MEMS_INT1_GPIO_Port GPIOE

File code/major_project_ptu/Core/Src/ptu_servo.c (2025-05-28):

/*
 * ptu_servo.c
 *
 *  Created on: May 3, 2025
 *      Author: maxyi
 */


#include "ptu_servo.h"

volatile uint16_t vertical_start_PWM = 1551;
volatile uint16_t horizontal_start_PWM = 1551;

// ==== Helper functions ===
uint8_t isNumeric(const char *str) {
    if (str == NULL || *str == '\0') return 0; // empty or NULL

    for (int i = 0; str[i] != '\0'; i++) {
        if (!isdigit((unsigned char)str[i])) {
            return 0;
        }
    }
    return 1;
}


void setServoPWM(uint16_t vertical_PWM, uint16_t horizontal_PWM){
	TIM2->CCR1 = vertical_PWM;
	TIM2->CCR2 = horizontal_PWM;
}


// ===== Initialize servo PWM and input capture for PTU =====
HAL_StatusTypeDef initialise_ptu_pwm(TIM_HandleTypeDef *htim1, TIM_HandleTypeDef *htim2) {
    HAL_StatusTypeDef return_value;

    // Start PWM on TIM2 Channel 1 (pan servo)
    return_value = HAL_TIM_PWM_Start(htim2, TIM_CHANNEL_1);
    if (return_value != HAL_OK) {
        return return_value;  // Return early on failure
    }

    // Start PWM on TIM2 Channel 2 (tilt servo)
    return_value = HAL_TIM_PWM_Start(htim2, TIM_CHANNEL_2);
    if (return_value != HAL_OK) {
        return return_value;  // Return early on failure
    }

    // Start Input Capture with interrupt on TIM1 Channel 1 (for feedback or sync)
    return_value = HAL_TIM_IC_Start_IT(htim1, TIM_CHANNEL_1);
    if (return_value != HAL_OK) {
        return return_value;  // Return early on failure
    }

    // Configure TIM2 auto-reload for 20ms period (50Hz PWM frequency, 1 count = 1us)
    htim2->Instance->ARR = 20000;

    // Enable Auto-Reload Preload (ARPE) for safe ARR updates at the end of PWM cycle
    htim2->Instance->CR1 |= TIM_CR1_ARPE;

    // Wait for 100ms to allow LIDAR (or other sensors) to initialize
    HAL_Delay(100);

    // Set initial servo PWM pulse widths for vertical and horizontal servos
    setServoPWM(vertical_start_PWM, horizontal_start_PWM);

    return HAL_OK;  // Initialization successful
}



// ===== Parse and apply servo commands from serial input =====
void servo_command_parser(SerialPort *serial_port) {
    char command_line[BUFFER_SIZE];

    // Copy received buffer into local command line string
    strcpy(command_line, serialGetReceivedBuffer(serial_port));

    // Parse pan and tilt PWM values separated by comma
    char *pan = strtok(command_line, ",");
    char *tilt = strtok(NULL, ",");

    // Validate that both values exist
    if (pan == NULL || tilt == NULL) return;

    // Check if both parsed strings are numeric
    if (isNumeric(pan) && isNumeric(tilt)) {
        int pwm1 = atoi(pan);
        int pwm2 = atoi(tilt);

        // Validate PWM value ranges before applying to servo registers
        if (pwm1 >= 1500 && pwm1 <= 2300 && pwm2 >= 1200 && pwm2 <= 1900) {
            TIM2->CCR1 = pwm1;  // Set pan servo PWM duty cycle
            TIM2->CCR2 = pwm2;  // Set tilt servo PWM duty cycle
        }
    }
}

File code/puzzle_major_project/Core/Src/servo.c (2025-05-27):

/*
 * servo.c
 *
 *  Created on: May 14, 2025
 *      Author: shuvayu
 */

// servo.c
// Module: Servo Control via TIM2 PWM on PA15
// Provides initialization of TIM2 for PWM output on PA15 and a helper
// to rotate the servo approximately 90 degrees by adjusting the duty cycle.

#include "stm32f303xc.h"
#include "servo.h"

// prototypes for our GPIO helpers (defined in gpio.c)
extern void enable_servo_clocks(void);
extern void configure_servo_gpio(void);

/*
Initialise TIM2 for PWM-based servo control on PA15 (TIM2_CH1).

Steps:
   1) Enable GPIOA and TIM2 clocks.
   2) Configure PA15 as AF1 (TIM2_CH1) output.
   3) Set prescaler and auto-reload for a 20 ms period (50 Hz).
   4) Configure channel 1 in PWM Mode 1 with preload enabled.
   5) Enable the channel 1 output.
   6) Enable auto-reload preload and start the timer.
   7) Set an initial 1.0 ms pulse width (servo 0° position).
*/
void Servo_Init(void) {
    // 1) Enable GPIOA & TIM2 clocks
    enable_servo_clocks();

    // 2) Configure PA15 for TIM2_CH1 alternate function
    configure_servo_gpio();

    // 3) Timer2 base: 48 MHz / (PSC+1) = 1 MHz timer clock
    TIM2->PSC = 47;              // prescaler
    TIM2->ARR = 20000 - 1;       // 20 ms period (50 Hz)
    TIM2->EGR = TIM_EGR_UG;      // force immediate update

    // 4) PWM mode 1 on CH1, enable preload
    TIM2->CCMR1 &= ~(TIM_CCMR1_CC1S
                   | TIM_CCMR1_OC1M
                   | TIM_CCMR1_OC1PE);
    TIM2->CCMR1 |=  (6U << TIM_CCMR1_OC1M_Pos)  // OC1M = 110 (PWM1)
                  | TIM_CCMR1_OC1PE;            // preload enable

    // 5) Enable channel 1 output
    TIM2->CCER |= TIM_CCER_CC1E;

    // 6) Enable auto-reload preload and start timer
    TIM2->CR1 |= TIM_CR1_ARPE
               | TIM_CR1_CEN;

    // 7) Set default 1.0 ms pulse width (0°)
    TIM2->CCR1 = 1000;
}

/*
- Rotate the servo to approximately 90 degrees.
- Writes a 1.8 ms pulse width to CCR1, corresponding to ~90°.
*/
void rotate_servo_90(void) {
    TIM2->CCR1 = 1800;
}

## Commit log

2025-04-18 Update C_Lab_Codes to match current local folder
2025-05-02 remove not working files
    [gpio.c, main.c, main.h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]
2025-05-03 Create CAD
2025-05-03 Cad files for sensor box
    [BASE_MTRX2700.STL, Flex pot placeholder.SLDPRT, Pressure Sensor Box.SLDPRT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]
2025-05-03 sensor box pic
2025-05-05 add step files
    [base_option2.STEP, crystal.STEP, hilt1.STEP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]
2025-05-05 ptu servo working, need refactor other code
2025-05-14 Add servo project W08-HAL-test to group repo
2025-05-14 servo code
2025-05-14 fix shuvayu's git push
    [main.c, main.h, servo.c]
2025-05-14 revert servo files
2025-05-17 game logic done, having trouble on serialisation of servo
2025-05-18 final main.c - working servo
2025-05-18 final servo.c - working servo
2025-05-18 final servo.h - working servo

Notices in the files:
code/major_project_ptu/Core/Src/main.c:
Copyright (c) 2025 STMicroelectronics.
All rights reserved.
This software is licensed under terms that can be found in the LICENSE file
